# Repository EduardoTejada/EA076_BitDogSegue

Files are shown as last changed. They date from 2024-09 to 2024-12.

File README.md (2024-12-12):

# BitDogSegue

## Sobre o projeto
O BitDogSegue é um robô seguidor de linha usando a placa BitDogLab como base e é fruto dos esforços realizados na disciplina EA076 - Laboratório de Sistemas Embarcados, ministrada na Unicamp pelo professor Fabiano Fruett. Desenvolvido pelos alunos Eduardo Pereira e José Braga, esse robô foi desenvolvido visando aprimorar os conhecimentos em eletrônica e programação (_hardware_ e _software) de estudantes e entusiastas nessa área.

Para mais detalhes sobre o projeto, acesse a documentação.

[Documentação](https://docs.google.com/document/d/1uC-1uOnyaNJ6YEM8gG9vPqVe9gIrEa1YJPF4Q7OL9hc/edit?usp=sharing)
[Apresentação](https://theresistance.my.canva.site/bitdogsegue)

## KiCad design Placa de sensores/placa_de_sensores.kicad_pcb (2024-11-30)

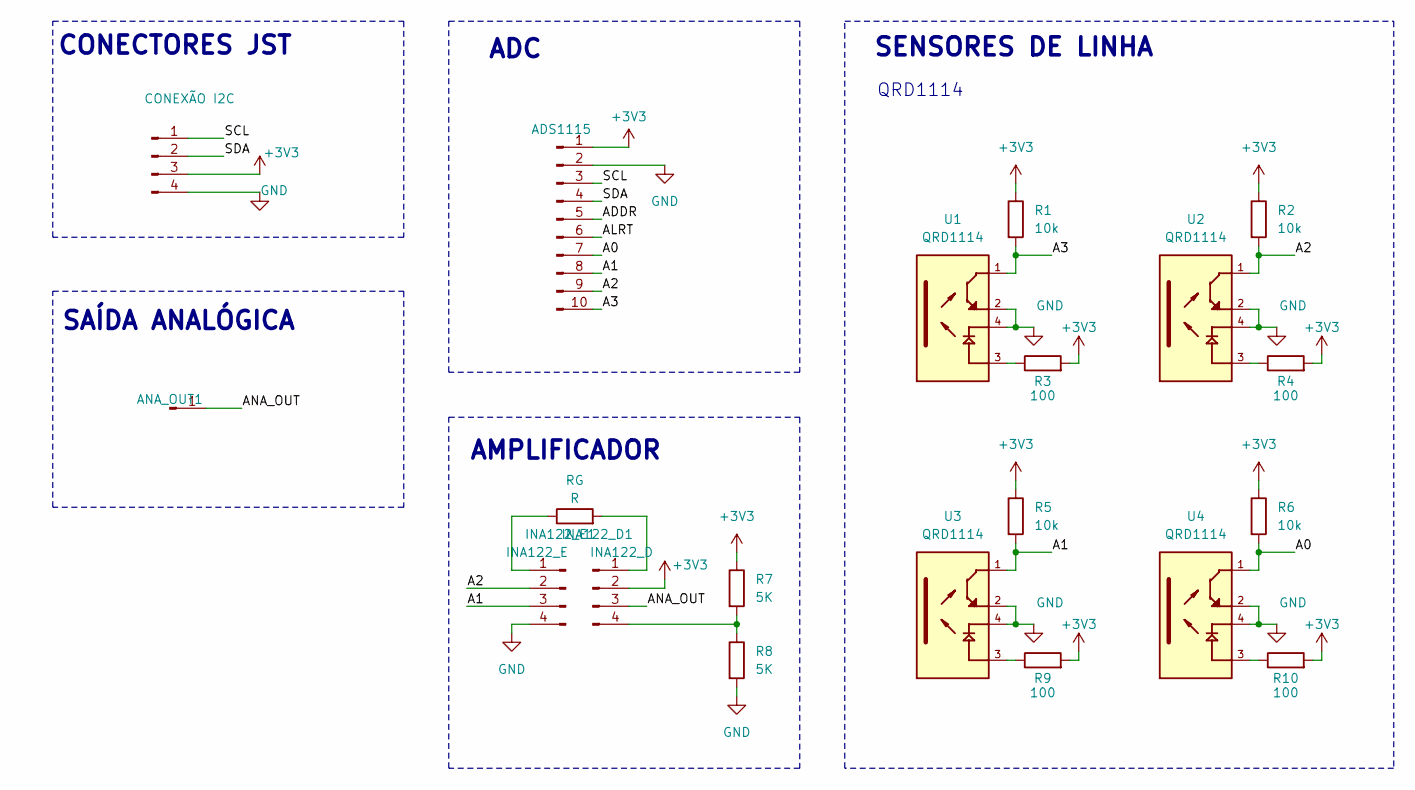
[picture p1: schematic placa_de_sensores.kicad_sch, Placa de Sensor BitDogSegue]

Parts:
ADS1115: ADS1115; PinHeader_1x10_P2.54mm_Vertical
ANA_OUT1: PinHeader_1x01_P1.00mm_Vertical
CONEXÃO-I2C1: CONEXÃO I2C; JST_EH_B4B-EH-A_1x04_P2.50mm_Vertical
INA122_D1: INA122_D; PinHeader_1x04_P2.54mm_Vertical
INA122_E1: INA122_E; PinHeader_1x04_P2.54mm_Vertical
R1, R2, R5, R6: 10k; R_Axial_DIN0207_L6.3mm_D2.5mm_P7.62mm_Horizontal
R3, R4, R9, R10: 100; R_Axial_DIN0207_L6.3mm_D2.5mm_P7.62mm_Horizontal
R7, R8: 5K; R_Axial_DIN0207_L6.3mm_D2.5mm_P7.62mm_Horizontal
RG: R; R_Axial_DIN0207_L6.3mm_D2.5mm_P7.62mm_Horizontal
U1, U2, U3, U4: QRD1114; ONS_QRD1114; PARTREV 1.3.0; DIGI-KEY_PART_NUMBER QRD1114-ND

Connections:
+3V3: ADS1115.1, CONEXÃO-I2C1.3, INA122_D1.2, R1.1, R2.1, R3.2, R4.2, R5.1, R6.1, R7.1, R9.2, R10.2; also elsewhere on the board
/A0: ADS1115.7, R6.2, U4.1
/A1: ADS1115.8, INA122_E1.3, R5.2, U3.1
/A2: ADS1115.9, INA122_E1.2, R2.2, U2.1
/A3: ADS1115.10, R1.2, U1.1
/ADDR: ADS1115.5
/ALRT: ADS1115.6
/SCL: ADS1115.3, CONEXÃO-I2C1.1
/SDA: ADS1115.4, CONEXÃO-I2C1.2
GND: ADS1115.2, CONEXÃO-I2C1.4, INA122_E1.4, R8.2, U1.2, U1.4, U2.2, U2.4, U3.2, U3.4, U4.2, U4.4
unnamed: ANA_OUT1.1, INA122_D1.3
unnamed 12: INA122_D1.1, RG.2; also elsewhere on the board
unnamed 13: INA122_D1.4, R7.2, R8.1; also elsewhere on the board
unnamed: INA122_E1.1, RG.1
unnamed: R3.1, U1.3
unnamed: R4.1, U2.3
unnamed: R9.1, U3.3
unnamed: R10.1, U4.3

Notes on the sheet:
ADC
SAÍDA ANALÓGICA
SENSORES DE LINHA
QRD1114
CONECTORES JST
AMPLIFICADOR

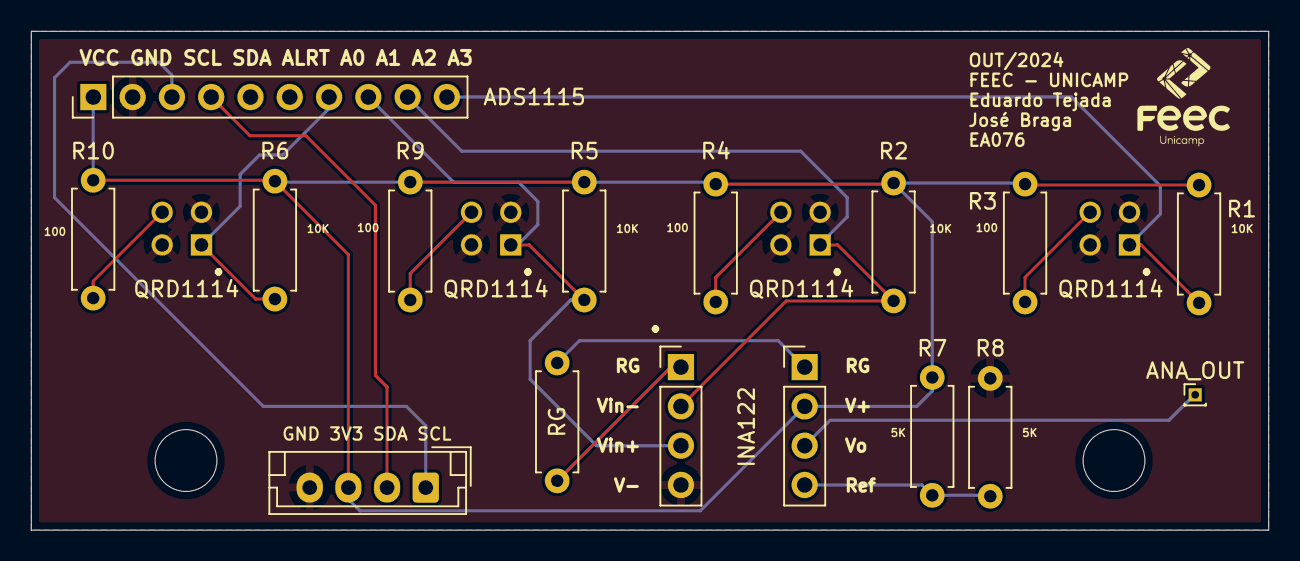
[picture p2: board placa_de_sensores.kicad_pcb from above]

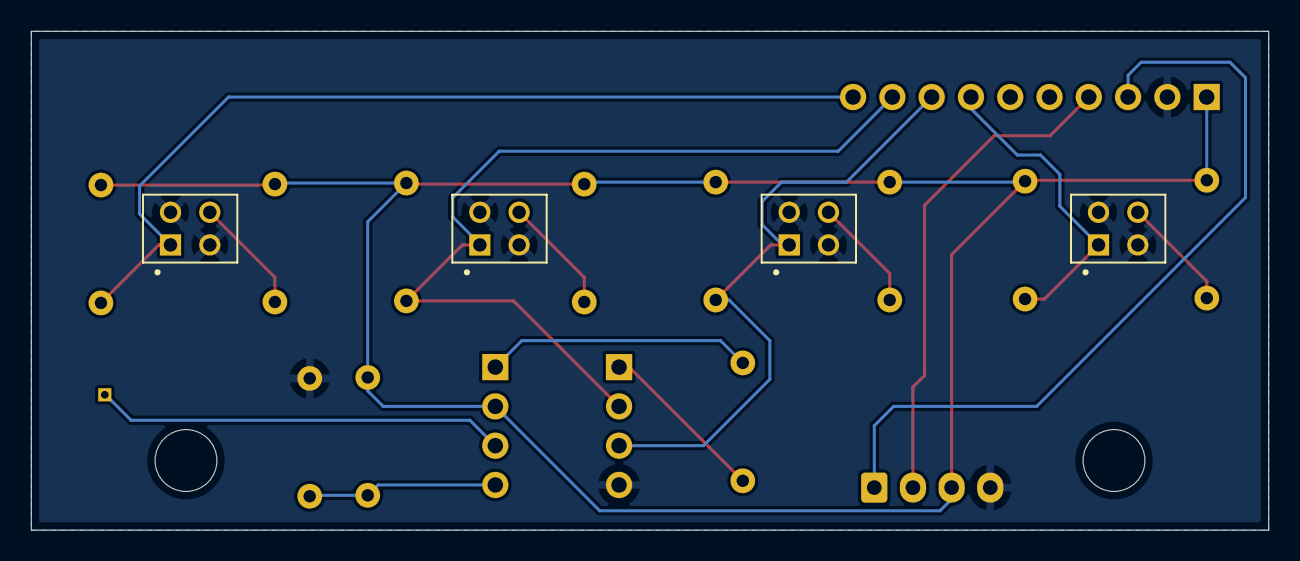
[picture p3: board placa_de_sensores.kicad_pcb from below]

Board: 2 copper layers, 80.0 x 32.2 mm, 20 parts (4 on the bottom side), 16 nets.

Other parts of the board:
ANA_OUT: PinHeader_1x01_P1.00mm_Vertical
INA122: INA122_D; PinHeader_1x04_P2.54mm_Vertical

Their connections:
+3V3: INA122.2; also elsewhere on the board
/ANA_OUT: ANA_OUT.1, INA122.3
unnamed 12: INA122.1; also elsewhere on the board
unnamed 13: INA122.4; also elsewhere on the board

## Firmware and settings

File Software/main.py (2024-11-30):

from machine import Pin, PWM, UART, I2C, SoftI2C
from ssd1306 import SSD1306_I2C
from time import sleep
from ads1x15 import ADS1115
import neopixel

linha = 0 # define a cor da linha da linha a ser seguida: 0 pra branco, 1 pra preto
limiar = 0.7 # limiar para diferenciar branco e preto na leitura digital

# Velocidade base inicial
base_speed = 50

# Definição das constantes PID
Kp = 10.0  # Constante proporcional 10
Ki = 0.5  # Constante integral
Kd = 1.5  # Constante derivativa

# Variáveis para o controle PID
integral = 0.0
last_error = 0.0

modo_de_operacao = 0
# 0: controle por celular
# 1: controle por bangbang
# 2: controle por PID

# Configuração I2C do ADS1115
i2c1_sda = Pin(2)  # GPIO2 como SDA
i2c1_scl = Pin(3)  # GPIO3 como SCL
i2c = I2C(1, scl=i2c1_scl, sda=i2c1_sda, freq=400000)
adc = ADS1115(i2c, address=0x48, gain=1)
rate = 4

# Configuração OLED
i2c = SoftI2C(scl=Pin(15), sda=Pin(14))
oled = SSD1306_I2C(128, 64, i2c)

# Configuração dos botões
button_a = Pin(5, Pin.IN, Pin.PULL_UP)
button_b = Pin(6, Pin.IN, Pin.PULL_UP)
estado_botao_a = 0
estado_botao_b = 0

# Configuração dos motores (TB6612FNG)
motor_in1_a = Pin(4, Pin.OUT)
motor_in2_a = Pin(9, Pin.OUT)
motor_pwm_a = PWM(Pin(8))
motor_pwm_a.freq(1000)
motor_pwm_a.duty_u16(0)  # Inicialmente desligado

motor_in1_b = Pin(18, Pin.OUT)
motor_in2_b = Pin(19, Pin.OUT)
motor_pwm_b = PWM(Pin(16))
motor_pwm_b.freq(1000)
motor_pwm_b.duty_u16(0)  # Inicialmente desligado

# Configuração do pino STBY para o TB6612FNG
stby = Pin(20, Pin.OUT)
stby.value(1)  # Ativar o driver

# Flag para indicar quando o robô deve parar
flag_parada = 0

# Configuração do UART para Bluetooth (HC-05)
uart = UART(0, baudrate=9600, tx=Pin(0), rx=Pin(1))

# Variáveis para leitura digital dos sensores de linha
sensor_esq_estado = sensor_dir_estado = 0

# Configuração da matriz de LEDs WS2812B
np = neopixel.NeoPixel(machine.Pin(7), 25)

it=50

# definir cores para os LEDs
BLU = (0, 0, 1*it)# BLUE
GRE = (0, 1*it, 0)# GREEN
RED = (1*it, 0, 0)#RED
YEL = (1*it, 1*it, 0)# YELLOW
MAGE = (1*it, 0, 1*it)# MANGENTA
CYA = (0, 1*it, 1*it)# CYAN
WHI = (1*it//3, 1*it//3, 1*it//3)# WHITE
BLA = (0, 0, 0)# BLACK

# Matrizes a serem mostradas no display 5x5
nothing = [
    [BLA, BLA, BLA, BLA, BLA],
    [BLA, BLA, BLA, BLA, BLA],
    [BLA, BLA, BLA, BLA, BLA],
    [BLA, BLA, BLA, BLA, BLA],
    [BLA, BLA, BLA, BLA, BLA]
]

all = [
    [WHI, WHI, WHI, WHI, WHI],
    [WHI, WHI, WHI, WHI, WHI],
    [WHI, WHI, WHI, WHI, WHI],
    [WHI, WHI, WHI, WHI, WHI],
    [WHI, WHI, WHI, WHI, WHI]
]

up_arrow = [
    [BLA, BLA, BLA, BLA, BLA],
    [BLA, BLA, BLA, BLA, BLA],
    [BLA, BLA, BLA, BLA, BLA],
    [BLA, WHI, BLA, WHI, BLA],
    [BLA, BLA, WHI, BLA, BLA]
]

down_arrow = [
    [BLA, BLA, WHI, BLA, BLA],
    [BLA, WHI, BLA, WHI, BLA],
    [BLA, BLA, BLA, BLA, BLA],
    [BLA, BLA, BLA, BLA, BLA],
    [BLA, BLA, BLA, BLA, BLA]
]

left_arrow = [
    [BLA, BLA, BLA, BLA, BLA],
    [BLA, BLA, BLA, WHI, BLA],
    [BLA, BLA, BLA, BLA, WHI],
    [BLA, BLA, BLA, WHI, BLA],
    [BLA, BLA, BLA, BLA, BLA]
]

right_arrow = [
    [BLA, BLA, BLA, BLA, BLA],
    [BLA, WHI, BLA, BLA, BLA],
    [WHI, BLA, BLA, BLA, BLA],
    [BLA, WHI, BLA, BLA, BLA],
    [BLA, BLA, BLA, BLA, BLA]
]

# Função para programar a matriz de LED's de maneira mais intuitiva
def mostrarMatriz(desenho):
    # definir a matriz 5x5
    led_matrix = desenho

    # inverter a matriz para que seja mostrada exatamente como é escrita
    inverted_matrix = led_matrix[::-1]
    inverted_matrix[0] = inverted_matrix[0][::-1]
    inverted_matrix[2] = inverted_matrix[2][::-1]
    inverted_matrix[4] = inverted_matrix[4][::-1]

    # exibir a matriz invertida nos LEDs
    for i in range(5):
        for j in range(5):
            np[i*5+j] = inverted_matrix[i][j]

    np.write()

mostrarMatriz(nothing)

# Função para debug dos sensores
def lerValoresCrus():
    for i, channel in enumerate([0, 1, 2, 3]):
        value = adc.read(rate=4, channel1=channel)
        print(f"Valor normalizado do canal {channel}: {value}")
    print('')

# Função para mostrar a linha a ser seguida na matriz de LED's
def mostrarLinhaMatriz(valores):
    follow_matrix = [
        [BLA, BLA, BLA, BLA, BLA],
        [BLA, BLA, BLA, BLA, BLA],
        [BLA, BLA, BLA, BLA, BLA],
        [BLA, BLA, BLA, BLA, BLA],
        [BLA, BLA, BLA, BLA, BLA]
    ]
    
    il = 200
    vetor = [3, 2, -1, 1, 0]
    for s in range(0, 5):
        if(s != 2):
            s2 = 0 if(valores[vetor[s]] > 1) else int(il*(1-valores[vetor[s]])//3)
            for s1 in range(0, 5):
                follow_matrix[s1][s] = (s2, s2, s2) # WHITE LINE
    mostrarMatriz(follow_matrix)

# Função para iniciar o display Oled
def iniciaOled():
    oled.fill(0)  # Limpar display
    oled.text("BitDogSegue", 0, 0)
    oled.text("Conecte o BT", 0, 10)
    oled.text("Aperte (A)", 0, 30)
    oled.text("para calibrar", 0, 40)
    oled.show()

# Função para mudar a velocidade do robô de -100 a 100
def set_motor_speed(motor, speed):
    dutycycle = int(speed * 65535 / 100)
    if motor == "A":
        if speed > 0:
            motor_in1_a.off()
            motor_in2_a.on()
        else:
            motor_in1_a.on()
            motor_in2_a.off()
        motor_pwm_a.duty_u16(dutycycle)
    elif motor == "B":
        if speed > 0:
            motor_in1_b.on()
            motor_in2_b.off()
        else:
            motor_in1_b.off()
            motor_in2_b.on()
        motor_pwm_b.duty_u16(dutycycle)


# Função para digitalizar os valores lidos pelo sensores analogicamente
def digitalizar():
    global linha, limiar, min_vals, max_vals, sensor_esq_estado, sensor_dir_estado
    # Ler e normalizar os valores dos sensores
    
    
    sensor_esq_estado = 0 if(linha == 1) else 1
    sensor_dir_estado = 0 if(linha == 1) else 1
    
    if((normalized_values[0] > limiar and linha == 1) or (normalized_values[0] < limiar and linha == 0)):
        sensor_esq_estado = linha
    if((normalized_values[3] > limiar and linha == 1) or (normalized_values[3] < limiar and linha == 0)):
        sensor_dir_estado = linha
    

# Função para fazer o controle bang-bang usando somente os sensores da ponta digitalizados
def controle_bang_bang():
    global base_speed, linha, flag_parada, limiar, min_vals, max_vals, sensor_esq_estado, sensor_dir_estado #sensor_esq_estado, sensor_dir_estado
    
    normalized_values = read_normalized_values(adc, min_vals, max_vals)
    mostrarLinhaMatriz(normalized_values)
    print(normalized_values)
    
    digitalizar()
    
    if(flag_parada == 0):
        # Lógica Bang-Bang
        if sensor_esq_estado == linha and sensor_dir_estado != linha:
            # Sensor da esquerda detecta linha, virar para a esquerda
            set_motor_speed("A", 0)
            set_motor_speed("B", base_speed)
        elif sensor_esq_estado != linha and sensor_dir_estado == linha:
            # Sensor da direita detecta linha, virar para a direita
            set_motor_speed("A", base_speed)
            set_motor_speed("B", 0)
        else:
            # Ambos os sensores detectam a linha, seguir em frente
            set_motor_speed("A", base_speed)
            set_motor_speed("B", base_speed)
    else:
        stop_robot()

# Função para o controle remoto para andar para frente
def andar_para_frente():
    set_motor_speed("A", base_speed)
    set_motor_speed("B", base_speed)

# Função para o controle remoto para andar para trás
def andar_para_tras():
    global base_speed
    dutycycle = int(base_speed * 65535 / 100)
    
    motor_in1_a.on()
    motor_in2_a.off()
    
    motor_in1_b.off()
    motor_in2_b.on()
    
    motor_pwm_a.duty_u16(dutycycle)
    motor_pwm_b.duty_u16(dutycycle)
    
# Função para o controle remoto para andar para esquerda
def andar_para_esquerda():
    global base_speed
    dutycycle = int(base_speed * 65535 / 100)
    
    motor_in1_a.on()
    motor_in2_a.off()
    
    motor_in1_b.on()
    motor_in2_b.off()
    
    motor_pwm_a.duty_u16(dutycycle)
    motor_pwm_b.duty_u16(dutycycle)

# Função para o controle remoto para andar para direita
def andar_para_direita():
    global base_speed
    dutycycle = int(base_speed * 65535 / 100)
    
    motor_in1_a.off()
    motor_in2_a.on()
    
    motor_in1_b.off()
    motor_in2_b.on()
    
    motor_pwm_a.duty_u16(dutycycle)
    motor_pwm_b.duty_u16(dutycycle)

# Função para parar o robô
def stop_robot():
    set_motor_speed("A", 0)
    set_motor_speed("B", 0)

# Função para enviar caracteres através da UART
def send_data(data):
    uart.write(data + '\n')  # Enviar dados com nova linha

def controle_bluetooth():
    global base_speed, flag_parada, modo_de_operacao, integral, last_error, Kp, Kd, Ki
    if uart.any():
        command = uart.readline().decode().strip()
        print(f"Received: {command}")
        if command == 'P':
            stop_robot()
            flag_parada = 1
            #send_data("Para")
        elif command == 'p':
            flag_parada = 0
            print("Continua")
            integral = 0
            last_error = 0
            #send_data("Continua")
        elif command.startswith('V'):
            c = command[0]
            try:
                speed0 = command[1]
                speed1 = command[2]
            except:
                return
            base_speed = int(speed0 + speed1)
            print(f"Velocidade: {speed0}{speed1}%")
            #send_data(f"Velocidade: {speed0}{speed1}%")
        elif command == 'R': # controle remoto
            modo_de_operacao = 0
            stop_robot()
        elif command == 'B': # bang bang
            modo_de_operacao = 1
        elif command == 'I': # pid
            integral = 0
            last_error = 0
            modo_de_operacao = 2
        elif(modo_de_operacao == 0 and flag_parada == 0):
            if command == 'F':
                mostrarMatriz(up_arrow)
                andar_para_frente()
                print("Frente")
            elif command == 'f':
                mostrarMatriz(nothing)
                stop_robot()
            elif command == 'T':
                mostrarMatriz(down_arrow)
                andar_para_tras()
                print("Tras")
            elif command == 't':
                mostrarMatriz(nothing)
                stop_robot()
            elif command == 'D':
                mostrarMatriz(right_arrow)
                andar_para_direita()
                print("Direita")
            elif command == 'd':
                mostrarMatriz(nothing)
                stop_robot()
            elif command == 'E':
                mostrarMatriz(left_arrow)
                andar_para_esquerda()
                print("Esquerda")
            elif command == 'e':
                mostrarMatriz(nothing)
                stop_robot()

def checarBotoes():
    global estado_botao_a, estado_botao_b, flag_parada, adc, integral, last_error
    
    lerBotoes()
    if(estado_botao_b):
        if(flag_parada):
            flag_parada = 0
        else:
            flag_parada = 1
            integral = 0.0
            last_error = 0.0
            stop_robot()
        sleep(0.2)

def lerBotoes():
    global estado_botao_a, estado_botao_b, flag_parada
    
    if button_a.value() == 0 and estado_botao_a == 0:
        estado_botao_a = 1
    elif button_a.value() == 1 and estado_botao_a == 1:
        estado_botao_a = 0
    
    if button_b.value() == 0 and estado_botao_b == 0:
        estado_botao_b = 1
    elif button_b.value() == 1 and estado_botao_b == 1:
        estado_botao_b = 0

# Função para normalizar um valor com base nos valores mínimo e máximo
def normalize(value, min_val, max_val):
    return (value - min_val) / (max_val - min_val)


# Função para calibrar os sensores e obter os valores mínimos e máximos
def calibrate_sensors(adc, samples=40):
    min_vals = [float('inf')] * 4
    max_vals = [-float('inf')] * 4
    
    ligado = 0
    
    for k in range(samples):
        for i, channel in enumerate([0, 1, 2, 3]):
            value = adc.read(rate=4, channel1=channel)
            if value < min_vals[i]:
                min_vals[i] = value
            if value > max_vals[i]:
                max_vals[i] = value
        print(min_vals, max_vals)
        sleep(0.1)
        print(k)
        if(k % 5 == 0):
            oled.fill(0)
            oled.text("Calibrando...", 0, 0)
            oled.text(str(k*2.5), 0, 10)
            oled.text("%", 30, 10)
            oled.show()
            if(ligado == 0):
                mostrarMatriz(all)
                ligado = 1
            else:
                mostrarMatriz(nothing)
                ligado = 0
    
    oled.fill(0)
    oled.text("Calibrado", 0, 0)
    oled.text("100", 0, 10)
    oled.text("%", 33, 10)
    oled.show()
    mostrarMatriz(all)
    sleep(0.5)
    mostrarMatriz(all)
    sleep(0.5)
    mostrarMatriz(nothing)
    return min_vals, max_vals

# Função para ler e normalizar os valores dos sensores
def read_normalized_values(adc, min_vals, max_vals):
    normalized_values = []
    for i, channel in enumerate([0, 1, 2, 3]):
        value = adc.read(rate=4, channel1=channel)
        norm_value = normalize(value, min_vals[i], max_vals[i])
        normalized_values.append(norm_value)
        #print(f"Valor normalizado do canal {channel}: {norm_value}")
    
    return normalized_values

def controle_pid():
    global integral, last_error, base_speed, sensores, min_vals, max_vals, kp, kd, ki, flag_parada
    
    # Ler e normalizar os valores dos sensores
    normalized_values = read_normalized_values(adc, min_vals, max_vals)
    
    if(not flag_parada):
        # Calcular a posição ponderada do robô com base nos sensores
        # Atribuir pesos aos sensores: mais à esquerda, maior peso negativo; mais à direita, maior peso positivo
        weights = [-3, -1, 1, 3]
        position = sum(weight * value for weight, value in zip(weights, normalized_values))
        
        # O erro é a posição ponderada em relação ao centro (0)
        error = position
        print("erro", error)
        # Calcular a parte proporcional
        P = Kp * error
        
        # Calcular a parte integral
        integral += error
        I = Ki * integral
        
        # Calcular a parte derivativa
        derivative = error - last_error
        D = Kd * derivative
        
        # Calcular a saída PID
        output = P + I + D
        
        # Atualizar o último erro
        last_error = error
        
        # Calcular as velocidades dos motores
        left_motor_speed = base_speed - int(output*0.8)
        if left_motor_speed > 100:
            left_motor_speed = 100 
        elif left_motor_speed < -100:
            right_motor_speed = -100
        
        right_motor_speed = base_speed + int(output*1.2)
        if right_motor_speed > 100:
            right_motor_speed = 100 
        elif right_motor_speed < -100:
            right_motor_speed = -100
        
        print("left: ", left_motor_speed)
        print("right: ", right_motor_speed)
        
        print(f"normalized_values: {normalized_values}")
        print("")
    
        # Definir a velocidade dos motores
        set_motor_speed("A", left_motor_speed)
        set_motor_speed("B", right_motor_speed)
    else:
        set_motor_speed("A", 0)
        set_motor_speed("B", 0)
    
    mostrarLinhaMatriz(normalized_values)

def esperarClickEmA():
    lerBotoes()
    while(estado_botao_a == 0):
        lerBotoes()
        sleep(0.01)

def setup():
    iniciaOled()
    esperarClickEmA() # aperte o botão A para começar a calibração

    min_vals, max_vals = calibrate_sensors(adc, 40) # etapa de calibração

    oled.fill(0)  # Limpar display
    oled.show()

def loop():
    controle_bluetooth()
    if(modo_de_operacao == 1):
        controle_bang_bang()
    elif(modo_de_operacao == 2):
        controle_pid()
    checarBotoes()
    
    sleep(0.01)  # Pequeno delay para evitar excesso de processamento
    
def main():
    setup()
    while(True):
        loop()

main()

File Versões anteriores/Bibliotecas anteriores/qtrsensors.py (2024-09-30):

"""
qtrsensors.py - easy library for Pololu Reflectance Sensors for MicroPython

* Author(s):    Braccio M.  from MCHobby (shop.mchobby.be).
                Meurisse D. from MCHobby (shop.mchobby.be).

See project source @ https://github.com/mchobby/micropython-zumo-robot
See example line_follower.py in the project source

History:
  21 jul 2021 - Braccio M. - Initial writing
  20 jul 2022 - Meurisse D. - Complete rewriting
  14 mar 2023 - Meurisse D. - Optimisation to avoids sensorValues argument (so memory fragmentation)
                              Append property values
"""
#
# The MIT License (MIT)
#
# Copyright (c) 2019 Meurisse D. for MC Hobby
#
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
__version__ = "0.0.4"
__repo__ = "https://github.com/mchobby/micropython-zumo-robot.git"

from micropython import const
from machine import Pin
import time
import gc

# QTRReadMode
# https://github.com/pololu/qtr-sensors-arduino/blob/master/QTRSensors.h
READMODE_OFF = const(0)
READMODE_ON = const(1)
READMODE_ON_AND_OFF = const(2)
READMODE_ODD_EVEN = const(3)
READMODE_ODD_EVEN_AND_OFF = const(4)
READMODE_MANUAL = const(5)

# QTREmitters
EMITTERS_ALL = const(0)
EMITTERS_ODD = const(1)
EMITTERS_EVEN= const(2)
EMITTERS_NONE= const(3)

NO_EMITTER_PIN = None

DEFAULT_TIMEOUT = const(2500) # uSec

MAX_SENSOR = const(31)

class CalibrationData:
	def __init__( self ):
		self.initialized = False
		self.minimum = None
		self.maximum = None

	def as_json( self ):
		import json
		_dict = {'initialized' : self.initialized, 'minimum' : self.minimum, 'maximum' : self.maximum }
		return json.dumps( _dict )

	def load_json( self, _str ):
		import json
		_dict = json.loads(_str)
		self.initialized = _dict['initialized']
		self.minimum = _dict['minimum']
		self.maximum = _dict['maximum']

class QTRSensors(object):
	def __init__(self,pins,emitterPin, evenEmitterPin=None, timeout=DEFAULT_TIMEOUT):
		assert len(pins) < MAX_SENSOR
		self._sensorPins = pins
		self._sensorCount = len( pins )
		self.__sensorValues = [0]*len( pins )
		self.__maxSensorValues = [0]*len( pins )
		self.__minSensorValues = [0]*len( pins )

		self._maxValue = timeout # the maximum value returned by readPrivate() AKA the timeout
		# self._samplesPerSensor = 4 # only used for analog sensors
		self.calibrationOn = CalibrationData()
		self.calibrationOff = CalibrationData()

		self._oddEmitterPin = emitterPin # also used for single emitter pin
		self._evenEmitterPin = evenEmitterPin
		self._emitterPinCount = 1 + (1 if evenEmitterPin != None else 0) # at least one
		self._oddEmitterPin.init( Pin.OUT )
		if self._evenEmitterPin != None:
			self._evenEmitterPin.init( Pin.OUT )

		self._dimmable = True
		self._dimmingLevel = 0

		self._lastPosition = 0

	@property
	def values( self ):
		return self.__sensorValues

	def __emittersOnWithPin( self, pin ): #pin:uint8_t return:uint16_t
		if self._dimmable and (pin.value() == 1) :
			# We are turning on dimmable emitters that are already on. To avoid messing
			# up the dimming level, we have to turn the emitters off and back on. This
			# means the turn-off delay will happen even if wait = false was passed to
			# emittersOn(). (Driver min is 1 ms.)
			pin.value( 0 )
			time.sleep_us(1200)

		pin.value(1)
		emittersOnStart = time.ticks_us()

		if self._dimmable and (self._dimmingLevel > 0):
			# noInterrupts();
			for i in range( self._dimmingLevel ): #(uint8_t i = 0; i < _dimmingLevel; i++)
				time.sleep_us(1)
				pin.value(0)
				time.sleep_us(1)
				pin.value(1)
			# interrupts();

		return emittersOnStart

	def __calibrateOnOrOff( self, calOn, mode ): # CalibrationData & calibration, QTRReadMode mode):
		# Handles the actual calibration, including (re)allocating and
		# initializing the storage for the calibration values if necessary.
		#DEBUG print("calibrateOnOrOff.in")
		for i in range( self._sensorCount ):
			self.__sensorValues[i] = 0
			self.__maxSensorValues[i] = 0
			self.__minSensorValues[i] = 0
		if calOn: # If we do calibrateOn
			calibration = self.calibrationOn
		else:
			calibration = self.calibrationOff

		# (Re)allocate and initialize the arrays if necessary.
		if not calibration.initialized:
			#DEBUG print("calibrateOnOrOff.calibration-init")
			# Looks not used! oldMaximum = list( calibration.maximum ) # Make a copy
			calibration.maximum = [0]*self._sensorCount

			# Looks not used! oldMinimum = list(calibration.minimum) # Make a copy
			calibration.minimum = [self._maxValue]*self._sensorCount
			calibration.initialized = True

		#DEBUG print("calibrateOnOrOff.10*read")
		for j in range( 10 ): # (uint8_t j = 0; j < 10; j++)
			# self.read( sensorValues, mode)# DEBUG NOK
			self.read( mode ) # DEBUG_NOK
			for i in range( self._sensorCount ): # (uint8_t i = 0; i < _sensorCount; i++)
				# set the max we found THIS time
				if (j == 0) or (self.__sensorValues[i] > self.__maxSensorValues[i]) :
					self.__maxSensorValues[i] = self.__sensorValues[i]
				# set the min we found THIS time
				if (j == 0) or (self.__sensorValues[i] < self.__minSensorValues[i]) :
					self.__minSensorValues[i] = self.__sensorValues[i]
		#DEBUG print("calibrateOnOrOff.record-min-max")
		# record the min and max calibration values
		for i in range( self._sensorCount ):
			# Update maximum only if the min of 10 readings was still higher than it
			# (we got 10 readings in a row higher than the existing maximum).
			if self.__minSensorValues[i] > calibration.maximum[i]:
				calibration.maximum[i] = self.__minSensorValues[i]

			# Update minimum only if the max of 10 readings was still lower than it
			# (we got 10 readings in a row lower than the existing minimum).
			if self.__maxSensorValues[i] < calibration.minimum[i]:
				calibration.minimum[i] = self.__maxSensorValues[i]
		gc.collect()
		#DEBUG print("calibrateOnOrOff.Collect+Out")

	def __readPrivate( self, start = 0, step = 1): # uint16_t * sensorValues, uint8_t start = 0, uint8_t step = 1
		# ONLY SUPPORTS the RC sensor (not analog ones)
		# Reads the first of every [step] sensors, starting with [start] (0-indexed, so start = 0 means start with the first sensor).
		# For example, step = 2, start = 1 means read the *even-numbered* sensors. start defaults to 0, step defaults to 1
		if self._sensorPins == None:
			return

		for i in range( start, self._sensorCount, step ): #(uint8_t i = start; i < _sensorCount; i += step)
			self.__sensorValues[i] = self._maxValue
			# make sensor line an output (drives low briefly, but doesn't matter)
			self._sensorPins[i].init( Pin.OUT )
			# drive sensor line high
			self._sensorPins[i].value( 1 )

		time.sleep_us(10) # charge lines for 10 us

		# disable interrupts so we can switch all the pins as close to the same time as possible
		# noInterrupts()

		# record start time before the first sensor is switched to input
		# (similarly, time is checked before the first sensor is read in the loop below)
		startTime = time.ticks_us()
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

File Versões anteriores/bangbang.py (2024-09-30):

from qtrsensors import QTRSensors
from machine import Pin, PWM, UART
from time import sleep

class ZumoReflectanceSensorArray( QTRSensors ):
    def __init__(self):
        arr = [ Pin( 2, Pin.IN ), Pin( 3, Pin.IN )]
        super().__init__( arr, Pin(0 ,Pin.OUT), timeout=2000)

class ZumoShield():
""" Create all in one class to control the Zumo """
    def __init__( self ):
        self.ir = ZumoReflectanceSensorArray()

z = ZumoShield()
z.ir.emittersOn()

import time
from machine import Pin, PWM, I2C, ADC, UART

# Configuração dos LEDs RGB
led_r = Pin(12, Pin.OUT)
led_g = Pin(13, Pin.OUT)
led_b = Pin(11, Pin.OUT)

# Configuração dos botões com resistores de pull-up internos
button_a = Pin(5, Pin.IN, Pin.PULL_UP)
button_b = Pin(6, Pin.IN, Pin.PULL_UP)
reset_button = Pin(30, Pin.IN)  # Pino RUN não precisa de pull-up

# Configuração dos buzzers
buzzer_a = PWM(Pin(21))
buzzer_b = PWM(Pin(10))

# Configuração do joystick
vrx = ADC(Pin(27))
vry = ADC(Pin(26))
button_sw = Pin(22, Pin.IN, Pin.PULL_UP)

# Configuração da matriz de LEDs WS2812B
import neopixel
np = neopixel.NeoPixel(Pin(7), 25)

# Configuração do display OLED I2C
from ssd1306 import SSD1306_I2C
i2c = I2C(0, scl=Pin(15), sda=Pin(14))
oled = SSD1306_I2C(128, 64, i2c)

# Configuração do microfone
mic = ADC(Pin(28))

# Configuração do UART para Bluetooth (HC-05)
uart = UART(0, baudrate=9600, tx=Pin(0), rx=Pin(1))

# Configuração dos motores (TB6612FNG)
motor_in1_a = Pin(4, Pin.OUT)
motor_in2_a = Pin(9, Pin.OUT)
motor_pwm_a = PWM(Pin(8))
motor_pwm_a.freq(1000)
motor_pwm_a.duty_u16(0)  # Inicialmente desligado

motor_in1_b = Pin(18, Pin.OUT)
motor_in2_b = Pin(19, Pin.OUT)
motor_pwm_b = PWM(Pin(16))
motor_pwm_b.freq(1000)
motor_pwm_b.duty_u16(0)  # Inicialmente desligado

# Configuração do pino STBY para o TB6612FNG
stby = Pin(20, Pin.OUT)
stby.value(1)  # Ativar o driver

# Variáveis globais dos sensores
sensor0 = 0
sensor1 = 0

# Velocidade base inicial
base_speed = 30000

def lerSensor():
    global sensor0, sensor1
    z.ir.read()
    z.ir.values[0] = sensor0
    z.ir.values[1] = sensor1

def set_motor_speed(motor, speed):
    if motor == "A":
        if speed > 0:
            motor_in1_a.on()
            motor_in2_a.off()
        else:
            motor_in1_a.off()
            motor_in2_a.on()
        motor_pwm_a.duty_u16(min(abs(speed), 65535))
    elif motor == "B":
        if speed > 0:
            motor_in1_b.on()
            motor_in2_b.off()
        else:
            motor_in1_b.off()
            motor_in2_b.on()
        motor_pwm_b.duty_u16(min(abs(speed), 65535))

def bang_bang_control():
    global base_speed

    # Leitura dos sensores
    lerSensor()

    # Lógica Bang-Bang
    if sensor0 > sensor1:
        # Sensor da esquerda detecta linha, virar para a esquerda
        set_motor_speed("A", base_speed)
        set_motor_speed("B", 0)
    elif sensor1 > sensor0:
        # Sensor da direita detecta linha, virar para a direita
        set_motor_speed("A", 0)
        set_motor_speed("B", base_speed)
    else:
        # Ambos os sensores detectam a linha, seguir em frente
        set_motor_speed("A", base_speed)
        set_motor_speed("B", base_speed)

def stop_robot():
    set_motor_speed("A", 0)
    set_motor_speed("B", 0)

def bluetooth_control():
    global base_speed
    if uart.any():
        command = uart.read().decode('utf-8').strip()
        if command == 'STOP':
            stop_robot()
        elif command.startswith('SPEED'):
            try:
                base_speed = int(command.split()[1])
                print(f"Velocidade base ajustada para: {base_speed}")
            except:
                print("Comando de velocidade inválido.")

while True:
    bluetooth_control()
    bang_bang_control()
    time.sleep(0.01)  # Pequeno delay para evitar excesso de processamento

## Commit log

2024-10-06 Update and rename teste sensor.py to main.py
2024-11-30 melhorias nos comentários, remoção de função não utilizadas
2024-11-30 Organizando arquivos
    [placa_de_sensores-B_Adhesive.gbr, placa_de_sensores-B_Courtyard.gbr, placa_de_sensores-B_Cu.gbr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]
2024-11-30 Update README.md
    Descrição do projeto e link para o relatório
2024-11-30 Update README.md
    Correção de gramática
